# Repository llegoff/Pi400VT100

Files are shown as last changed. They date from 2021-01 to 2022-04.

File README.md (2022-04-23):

[:fr:](LISEZMOI.md) [:uk:](README.md)

# Pi400VT100
VGA & Serial interface for Raspberry Pi 400

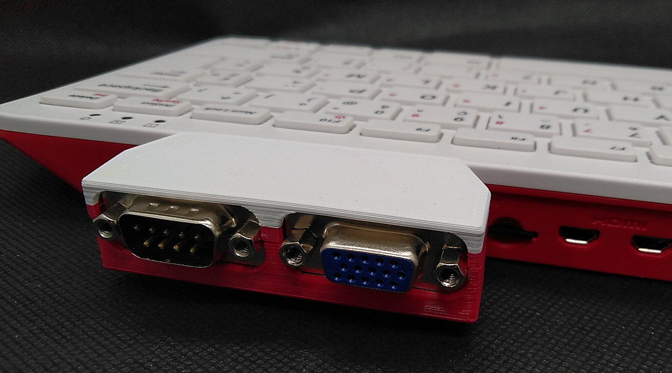
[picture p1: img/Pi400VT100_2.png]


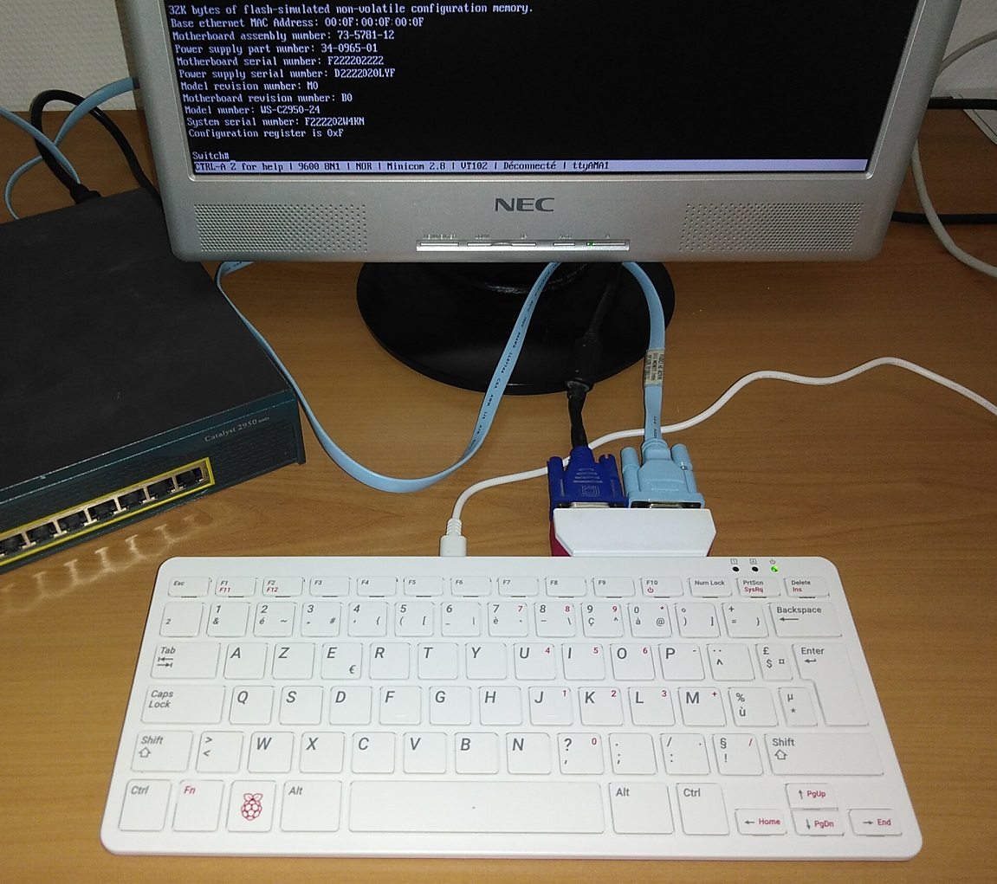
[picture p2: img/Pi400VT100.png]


## DPI (Display parallel Interface)
Like [VGA666](https://github.com/fenlogic/vga666), this pcb uses dpi interface (in mode 7, and 3x4bits to free gpio 12 to 15)

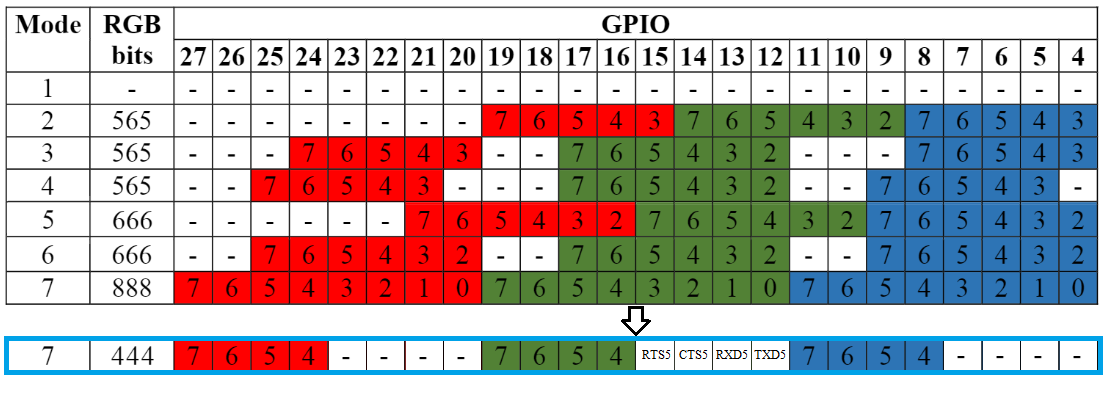
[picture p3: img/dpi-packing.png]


see https://www.raspberrypi.org/documentation/hardware/raspberrypi/dpi/README.md

only the necessary bits of the dpi are redirected to the 40-pin GPIO port, with the 'gpio=2-3,8-11,16-19,24-27=a2' line on config.txt

/boot/config.txt
    
    # replace dtoverlay=vc4-kms-v3d with
    dtoverlay=vc4-fkms-v3d
    
    # disable i2c, pin use by h-sync & v-sync
    dtparam=i2c_arm=off
    gpio=2-3,8-11,16-19,24-27=a2
    dpi_output_format=0x17
    enable_dpi_lcd=1
    display_default_lcd=1
    dpi_group=2
    dpi_mode=16
    #---------------- dpi_mode line ---------------------
    #---> 640x480 60hz    dpi_mode=4
    #---> 800x600 60hz    dpi_mode=9
    #---> 1024x768 60hz   dpi_mode=16
    #---> 1280x768 60hz   dpi_mode=23
    #---> 1280x800 60hz   dpi_mode=28
    #---> 1280x960 60hz   dpi_mode=32
    #---> 1280x1024 60hz  dpi_mode=35
    #---> 1360x768 60hz   dpi_mode=39
    #---> 1366x768 60hz   dpi_mode=81
    #---> 1400x1050 60hz  dpi_mode=42
    #---> 1440x900 60hz   dpi_mode=47
    #---> 1600x1200 60hz  dpi_mode=51
    #---> 1680x1050 60hz  dpi_mode=58
    #---> 1920x1080 60hz  dpi_mode=82
    #---> 1920x1200 60hz  dpi_mode=69
    #---> 1920x1440 60hz  dpi_mode=73

## Serial port

    # Enable Uart /dev/ttyAMA1, on pin 12,13,14,15
    dtoverlay=uart5,ctsrts

## Schematic
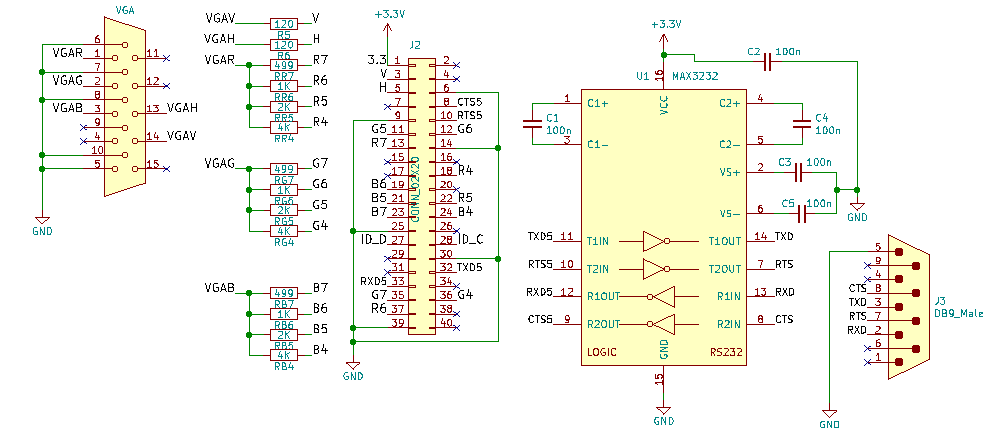
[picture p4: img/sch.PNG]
sch


## PCB
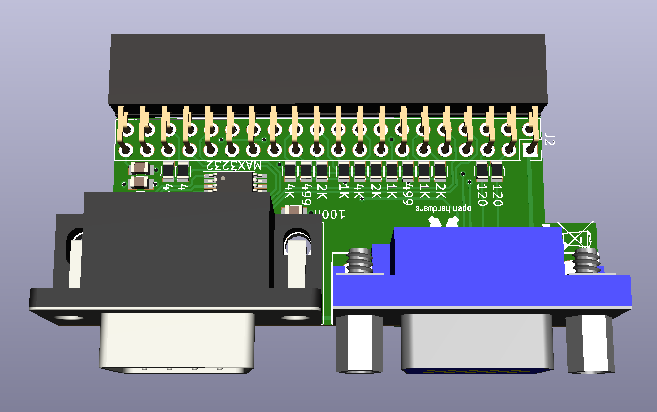
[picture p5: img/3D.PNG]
pcb


## Installation
copy content of [config-example.txt](img/config-example.txt?raw=true) to /boot/config.txt

install Minicom

    sudo apt update
    sudo apt upgrade
    sudo apt install minicom
    
run minicom with default config

    minicom -D /dev/ttyAMA1

run minicom 9600bps 8bit 

    minicom -b 9600 -8 -D /dev/ttyAMA1

## Révision
rev1
  bad space between VGA and DB9 connectors
  
rev2

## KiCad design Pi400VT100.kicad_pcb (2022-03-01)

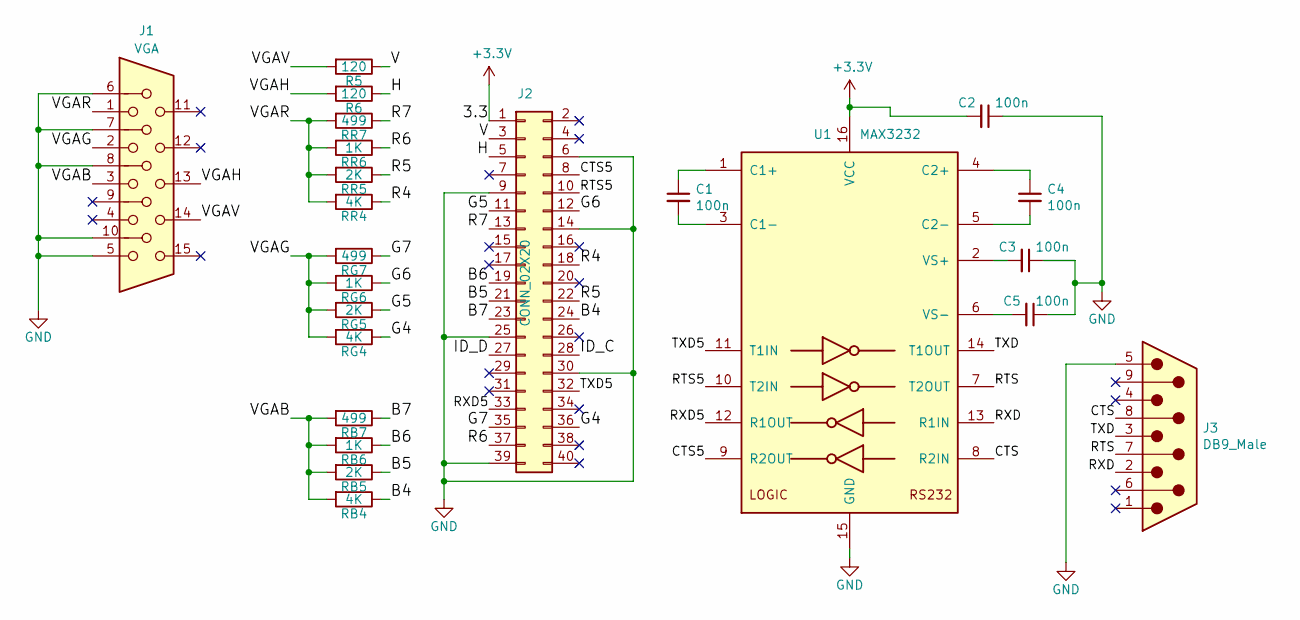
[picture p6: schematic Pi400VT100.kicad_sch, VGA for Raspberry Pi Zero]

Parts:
C1, C2, C3, C4, C5: 100n; C_0805
J1: VGA; DB_15F-VGA
J2: CONN_02X20; Socket_Strip_Straight_2x20_Pitch2.54mm
J3: DB9_Male; DB9MC
R5, R6: 120; R_0805
RB4: 4K; R_0805
RB5: 2K; R_0805
RB6: 1K; R_0805
RB7: 499; R_0805
RG4: 4K; R_0805
RG5: 2K; R_0805
RG6: 1K; R_0805
RG7: 499; R_0805
RR4: 4K; R_0805
RR5: 2K; R_0805
RR6: 1K; R_0805
RR7: 499; R_0805
U1: MAX3232; TSSOP-16_4.4x5mm_Pitch0.65mm

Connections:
+3V3: C2.2, J2.1, U1.16 (VCC)
/B4: J2.24, RB4.1
/B5: J2.21, RB5.1
/B6: J2.19, RB6.1
/B7: J2.23, RB7.1
/CTS: J3.8, U1.8 (R2IN)
/CTS5: J2.8, U1.9 (R2OUT)
/G4: J2.36, RG4.1
/G5: J2.11, RG5.1
/G6: J2.12, RG6.1
/G7: J2.35, RG7.1
/H: J2.5, R6.1
/ID_C: J2.28
/ID_D: J2.27
/R4: J2.18, RR4.1
/R5: J2.22, RR5.1
/R6: J2.37, RR6.1
/R7: J2.13, RR7.1
/RTS: J3.7, U1.7 (T2OUT)
/RTS5: J2.10, U1.10 (T2IN)
/RXD: J3.2, U1.13 (R1IN)
/RXD5: J2.33, U1.12 (R1OUT)
/TXD: J3.3, U1.14 (T1OUT)
/TXD5: J2.32, U1.11 (T1IN)
/V: J2.3, R5.1
/VGAB: J1.3, RB4.2, RB5.2, RB6.2, RB7.2
/VGAG: J1.2, RG4.2, RG5.2, RG6.2, RG7.2
/VGAH: J1.13, R6.2
/VGAR: J1.1, RR4.2, RR5.2, RR6.2, RR7.2
/VGAV: J1.14, R5.2
GND: C2.1, C3.1, C5.1, J1.5, J1.6, J1.7, J1.8, J1.10, J2.6, J2.9, J2.14, J2.25, J2.30, J2.39, J3.5, U1.15 (GND)
unnamed: C1.1, U1.1 (C1+)
unnamed: C1.2, U1.3 (C1-)
unnamed: C3.2, U1.2 (VS+)
unnamed: C4.1, U1.4 (C2+)
unnamed: C4.2, U1.5 (C2-)
unnamed: C5.2, U1.6 (VS-)

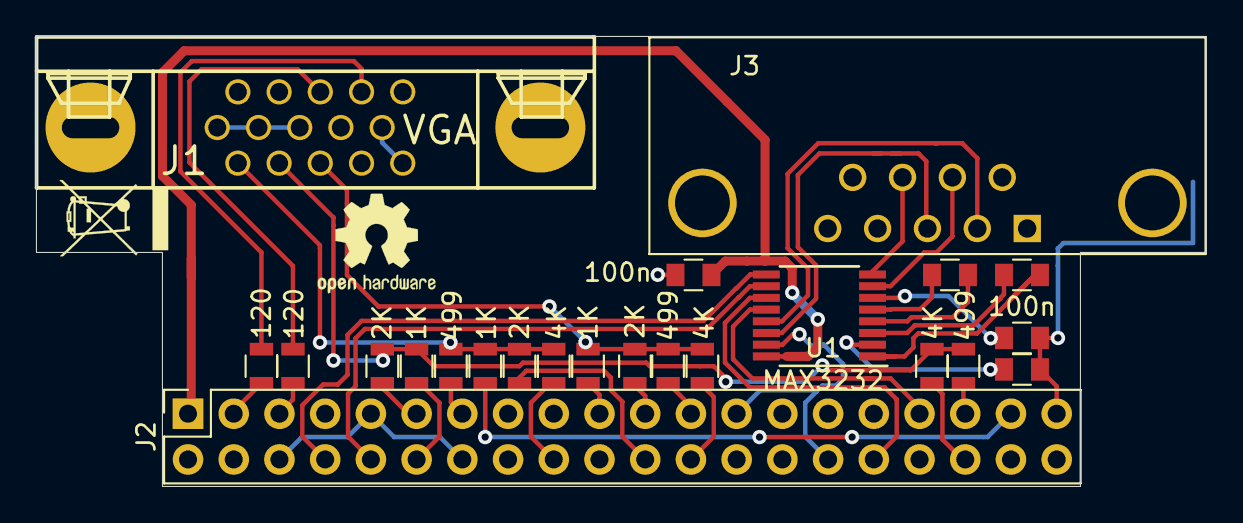
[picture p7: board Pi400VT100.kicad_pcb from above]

Board: 2 copper layers, 65.0 x 25.0 mm, 23 parts (0 on the bottom side), 35 nets.
